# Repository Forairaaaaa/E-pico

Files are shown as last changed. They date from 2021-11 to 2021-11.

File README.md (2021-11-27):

# E-pico

E-pico 是稚晖君项目 [ESP32-PicoDK](https://github.com/peng-zhihui/ESP32-PicoDK) 的个人衍生版本，意在刚学AD后练手...  学完更加坚定等 Kicad6 了~

与原版相比，阉割CAN、IMU功能，所有容阻更换 0603 封装，CP2102更换为CH340N。

PCB Layout 方面，主要元件的分布上参考原版，布线自由发挥..  故引出引脚与原版不同。

- 优点：元件全部分布在顶层，方便手工贴片和加热台焊接
- 缺点：
  1. 替换CP2102代价，需手动进入下载模式下载程序（这点主要是👴菜
  2. 第一次基于裸芯片画 ESP32 开发板，仅供参考

#### 开发板资源

- ESP32-PICO-D4 主控，兼容 Arduino、ESP-IDF 平台
- 128x80 I2C OLED 屏幕
- TypeC 接口 USB-TTL
- 2.4G陶瓷天线
- 引出大部分引脚

#### 引脚定义

- OLED 屏幕的 I2C 引脚定义与原版一致，即：
  1. SCL：IO22
  2. SDA：IO21
- 板载 led：IO2

#### 焊接注意

- 建议钢网 + 加热台
- 开发板背面的 **VDD_EN** 焊盘封装为主控的电源使能，建议焊接完成后先上电测试，电源确认无异后短接焊盘（0R电阻、焊锡）
- 我选购的0.78寸12880 OLED 由于不自带升压，5v供电比较暗，选购时注意

#### 程序下载

1. 与同类 ESP32 开发板类似，使用板载的 TypeC 接口与 PC 连接
2. **按住 IO0 按钮的同时，按下 RES 按键（复位键），以进入下载模式**
3. 在平台上点击烧写（ArduinoIDE、PlatformIO...）
4. **烧写完成后再按下 RES 按键退出下载模式**
5. 下载完成

#### 参考程序

由于屏幕接口与稚晖君原版一致，故 OLED 使用参考[原版](https://github.com/peng-zhihui/ESP32-PicoDK/tree/main/2.Samples)即可，其余可参考[ESP32官方Arduino仓库](https://github.com/espressif/arduino-esp32/tree/master/libraries)

#### 参考图片                                                                                                                                                     

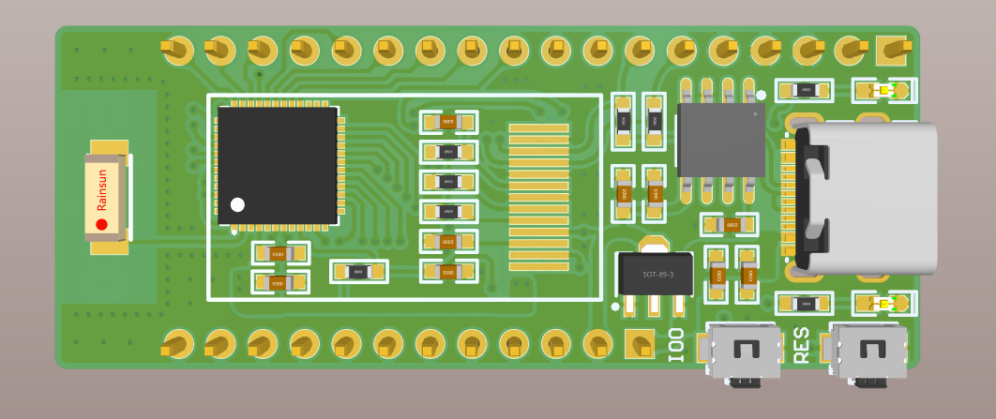
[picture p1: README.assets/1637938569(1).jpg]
1637938569(1)


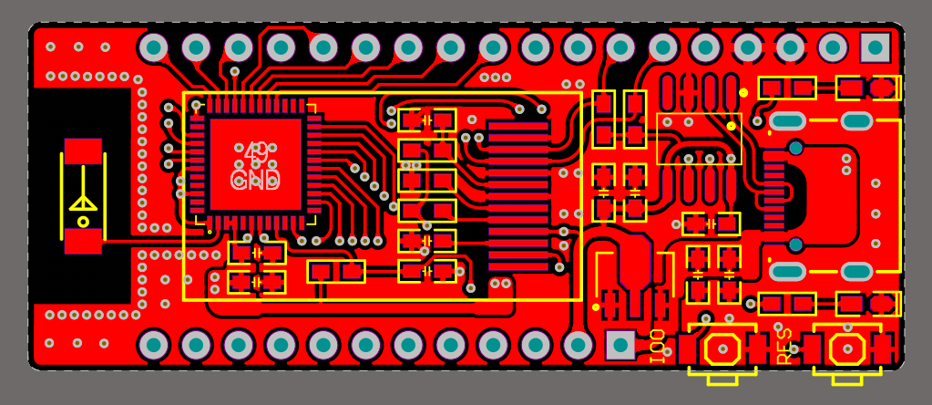
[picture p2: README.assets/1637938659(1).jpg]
1637938659(1)


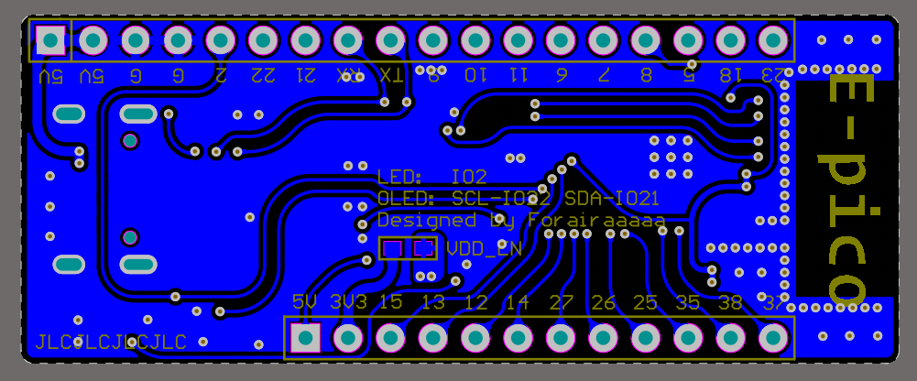
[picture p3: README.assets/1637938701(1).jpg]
1637938701(1)


#### 原理图

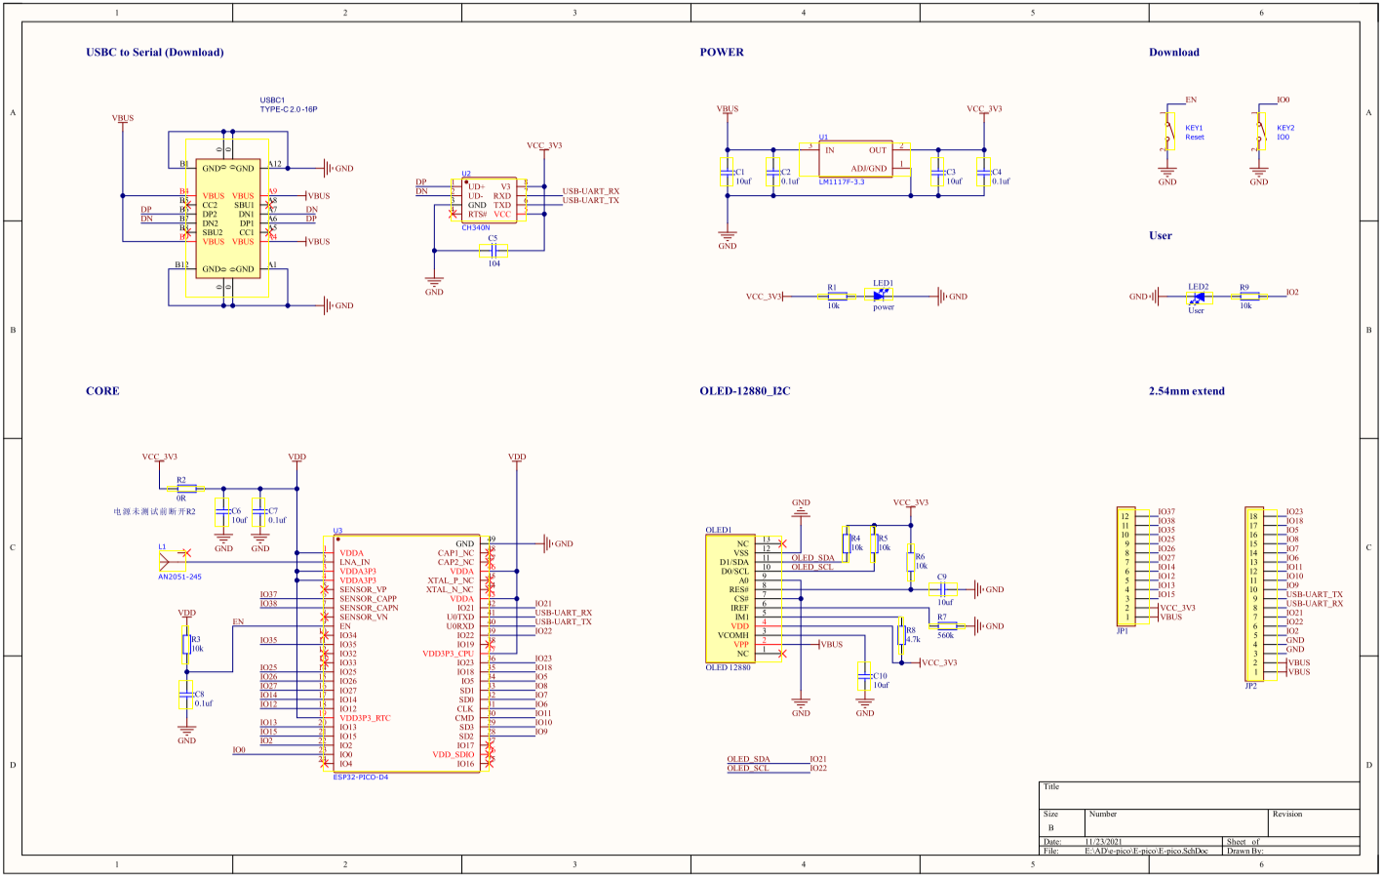
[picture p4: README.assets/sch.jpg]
sch


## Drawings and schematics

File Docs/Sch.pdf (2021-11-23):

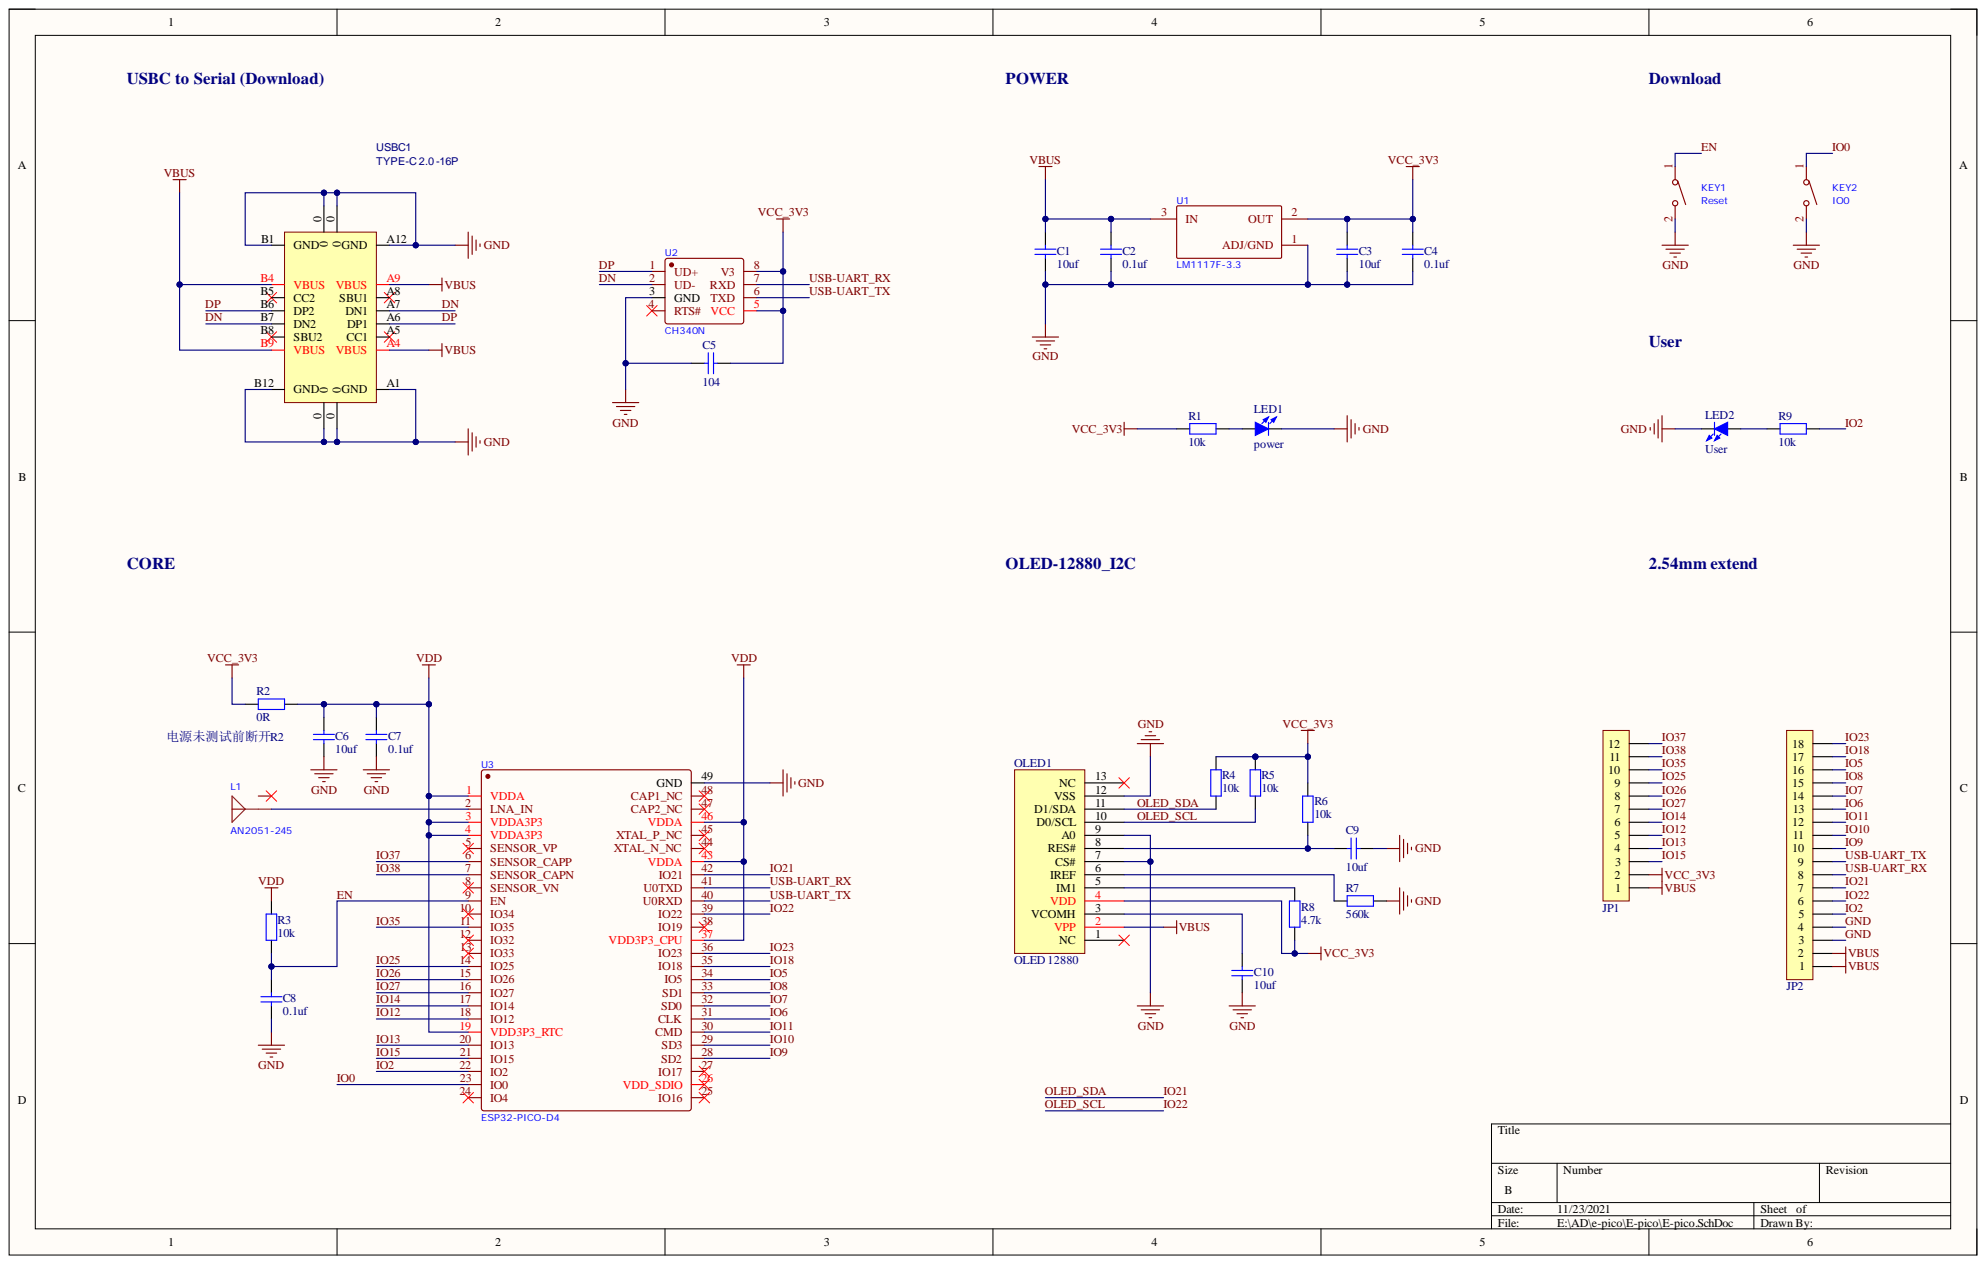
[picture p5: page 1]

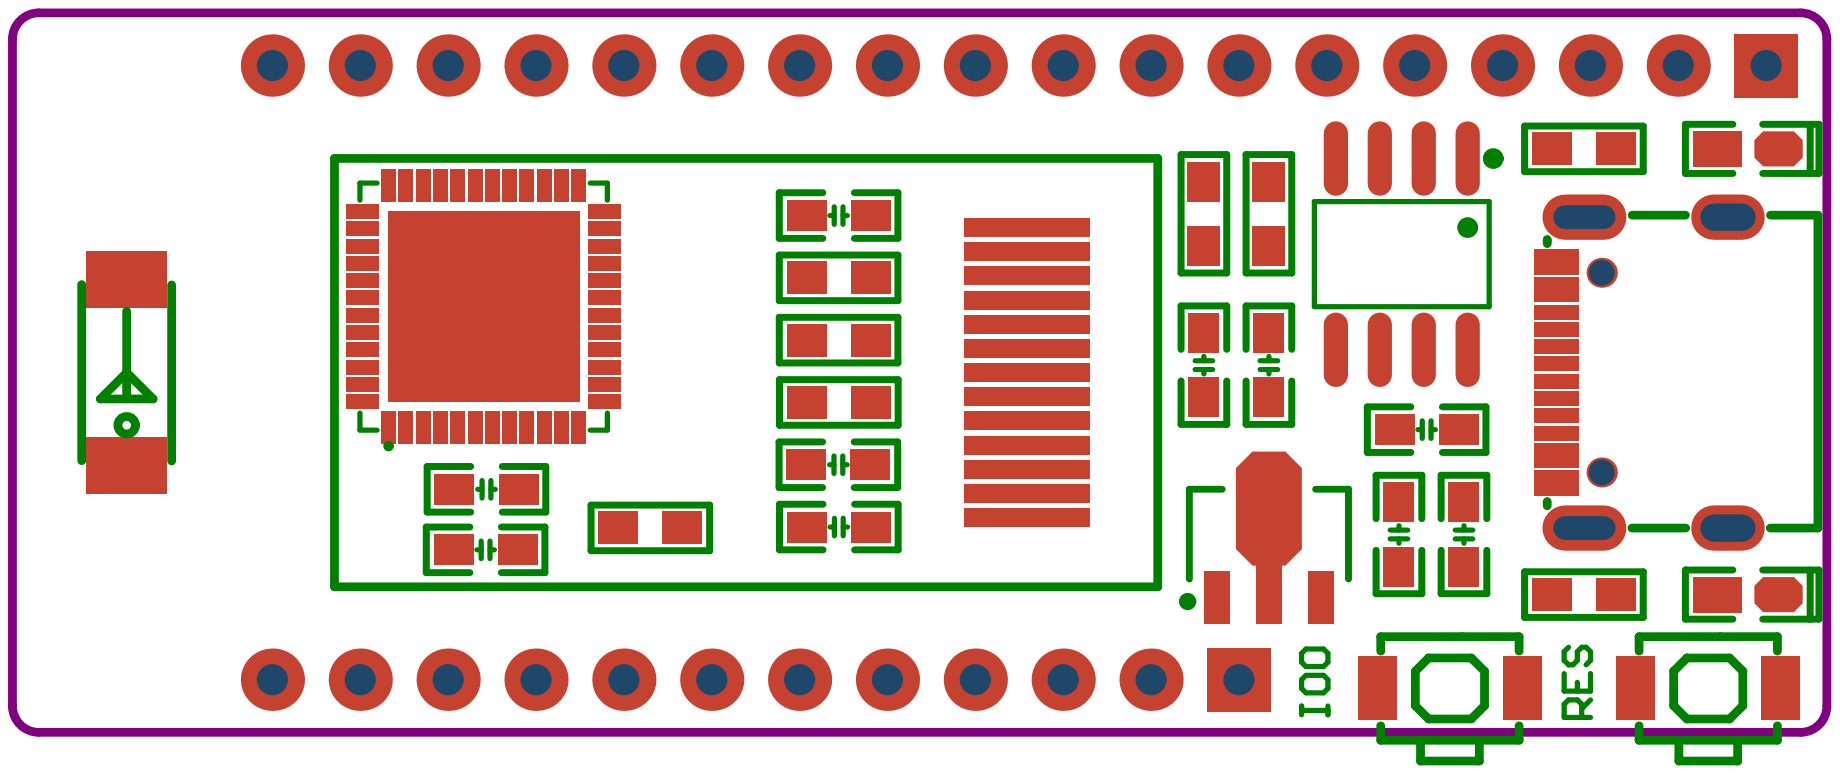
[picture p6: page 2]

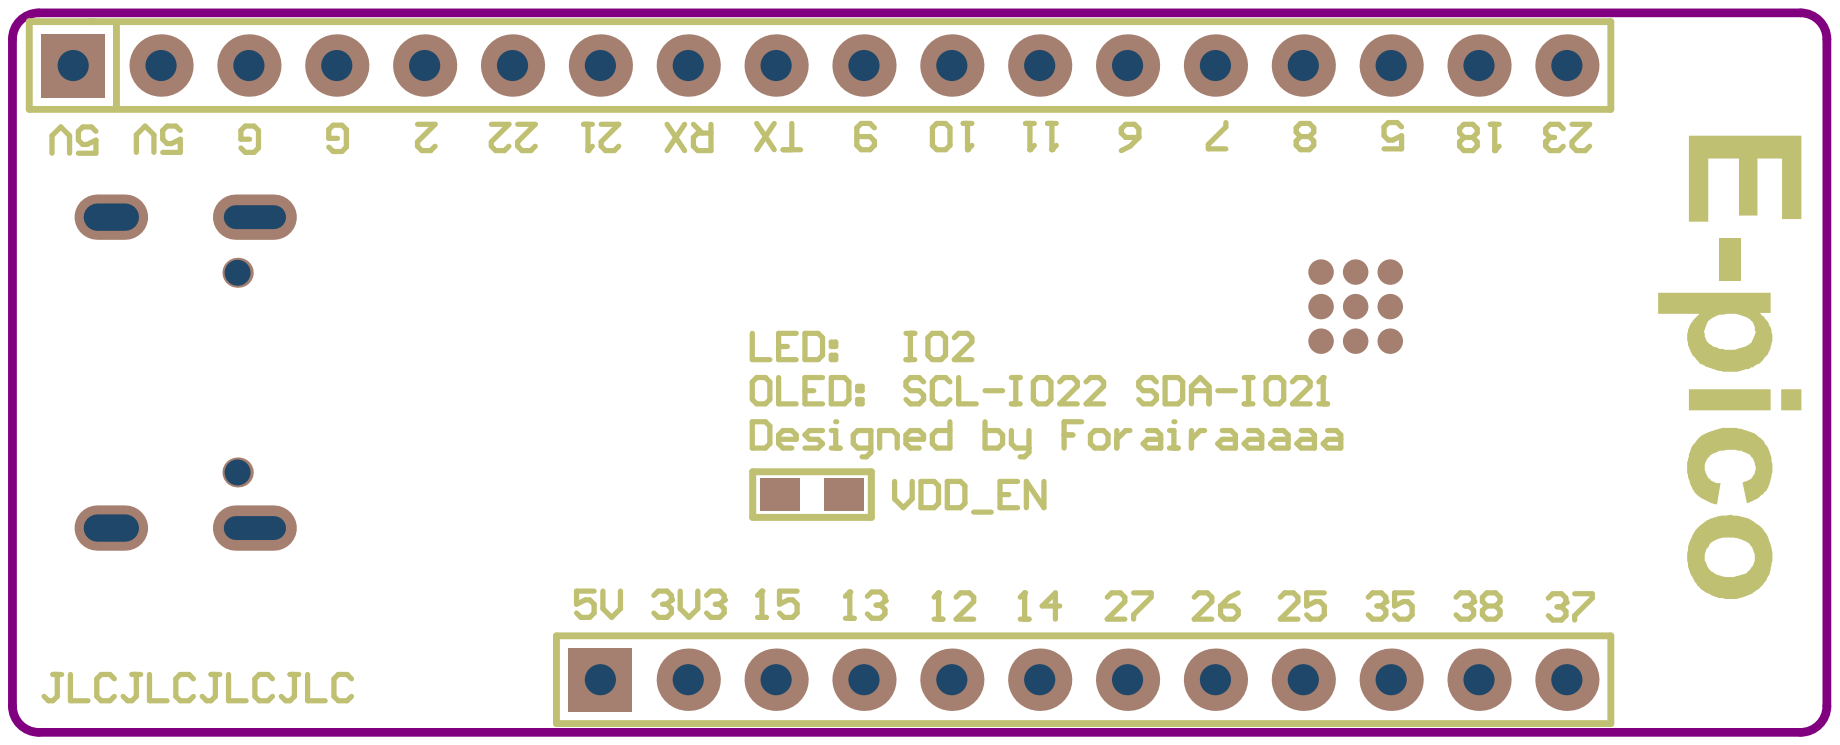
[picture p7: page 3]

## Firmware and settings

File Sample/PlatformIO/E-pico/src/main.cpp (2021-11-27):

#include <Arduino.h>
#include <U8g2lib.h>


U8G2_SH1107_128X80_F_HW_I2C u8g2(U8G2_R1, /* reset=*/ U8X8_PIN_NONE, /* clock=*/ 22, /* data=*/ 21);


void led( void *pvParameters );
void oled( void *pvParameters );

void setup() {

    // Serial
    Serial.begin(115200);
    Serial.println("E-pico");

    // OLED task create
    xTaskCreatePinnedToCore(oled, "oledTask", 2048, NULL, 3, NULL, 0);
    // Test led task create
    xTaskCreatePinnedToCore(led, "ledTask", 1024, NULL, 0, NULL, 0);
}


void loop() {
}


// led Task
void led( void *pvParameters ) {
    // led setup
    ledcSetup(0, 12000, 8);
    ledcAttachPin(2, 0);

    for(;;) {
        // Forward
        for(int i = 0; i<255; i++) {
            ledcWrite(0, i); 
            delay(5);
        }
        delay(300);
        // Backward
        for(int i = 255; i>0; i--) {
            ledcWrite(0, i); 
            delay(5);
        }
    }
}


// OLED Task
void oled( void *pvParameters ) {
    char buffer[100];
    int i = 1;

    // U8g2 setup
    u8g2.begin();
    u8g2.clearBuffer();
    u8g2.setFont(u8g2_font_ncenB24_tr);
    u8g2.drawStr(10,47,"E-pico");
    u8g2.sendBuffer();
    delay(1500);

    for(;;) {
        // Update OLED
        u8g2.clearBuffer();

        u8g2.setFont(u8g2_font_ncenB08_tr);
        u8g2.drawStr(0,8,"E-pico:");
        u8g2.drawStr(0,22,"OLED display test");

        sprintf(buffer, "%d", i++);
        u8g2.setFont(u8g2_font_ncenB24_tr);
        u8g2.drawStr(0,67,buffer);

        u8g2.sendBuffer();
        delay(10);
    }
}

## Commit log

2021-11-20 basic push
    [E-pico.PcbDoc, E-pico.PcbLib, E-pico.SchDoc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]
2021-11-20 add 2.54 header
    [E-pico_V1.PrjPcb]
2021-11-21 add oled-12880 into lib
    [E-pico.PcbDoc, E-pico.PcbLib, E-pico.SchDoc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]
2021-11-21 cut the board out!
    [E-pico.PcbDoc, E-pico.PcbLib, E-pico.SchDoc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]
2021-11-22 lock and set rules
    [E-pico.PcbDoc]
2021-11-22 change to smaller key, brings a user key and a led.
    [E-pico.PcbDoc, E-pico.PcbLib, E-pico.SchDoc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]
2021-11-22 power part almost done
    [E-pico.PcbDoc, E-pico.SchDoc]
2021-11-22 normal shit
    [E-pico.PcbDoc]
2021-11-23 so damn hard to keep using 曲线 all the times
    [E-pico.PcbDoc, E-pico.SchDoc]
2021-11-23 new shit
    [E-pico.PcbDoc, E-pico.SchDoc]
2021-11-23 done with gnd
    [E-pico.SchDoc]
2021-11-23 Done V1.0
    [E-pico.SchDoc]
2021-11-23 First version -- V1.0
    [E-pico.GBL, E-pico.GBO, E-pico.GBP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]
2021-11-23 BUG FIXED, Verison V1.1
    [E-pico_V1.PrjPcb]
2021-11-23 V1.1 Final update
    [E-pico_V1.PrjPcb]
2021-11-23 V1.1 Final update.
    [E-pico.GBL, E-pico.GBO, E-pico.GBP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]
2021-11-26 new location
    [E-pico.GBL, E-pico.GBO, E-pico.GBP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]
2021-11-26 new direction
    [E-pico.GBL, E-pico.GBO, E-pico.GBP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]
2021-11-27 add test samples
    [E-pico.GBL, E-pico.GBO, E-pico.GBP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]
2021-11-27 add TestSamples/PlatformIO/E-pico/lib/U8g2 submodule.
2021-11-27 删除子模块 TestSamples/PlatformIO/E-pico/lib/U8g2
2021-11-27 add TestSamples/PlatformIO/E-pico/lib/U8g2_Arduino submodule.
2021-11-27 add test sample
